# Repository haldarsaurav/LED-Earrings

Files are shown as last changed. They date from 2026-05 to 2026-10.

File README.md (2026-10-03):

# Motion-water LED earrings

This repository contains a design-start package for a rechargeable pair of 8 × 10 RGB pixel earrings. The proposed first wearable revision adds an accelerometer so a blue waterline reacts to tilt. It is intended as a personal gift project.

- [Selected plan](FINAL_PLAN.md)
- [Rev B electrical architecture, net names and PCB study](hardware/rev_b/README.md)
- [Compiled ATtiny1616 firmware and animated water preview](firmware/rev_b/README.md)
- [Parametric cases and rendered STL fit dummies](mechanical/rev_b/README.md)
- [Home programming and first-article checks](PROGRAM_AND_TEST.md)
- [Editable EasyEDA Rev B project](https://easyeda.com/haldarsaurav123456/led-earrings-rev-b-motion-water)

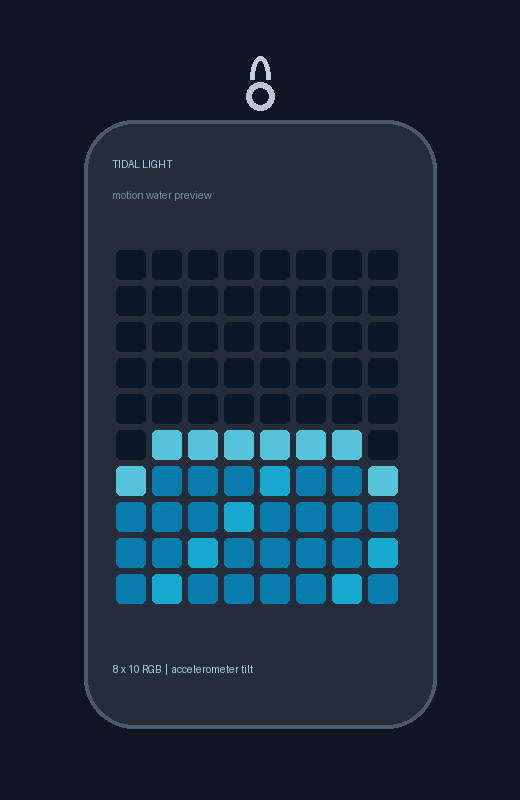
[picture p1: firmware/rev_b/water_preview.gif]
Simulated motion water effect


**Build status:** EasyEDA contains a partial schematic with the MCU, accelerometer, charger, regulator and two LEDs, plus a provisional 26 × 42 mm PCB outline with five footprints. No electrical nets, 80-LED chain, final placement or routing have been completed. Firmware compiles and a `.hex` is included, but has not been flashed to hardware. The three STL files are fit dummies; the PCB and charging dock are not ready to fabricate or use.

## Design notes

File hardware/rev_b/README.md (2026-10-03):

# Rev B — motion water earring, design-start package

**Status: architectural schematic and placement study, with a saved [EasyEDA Rev B project](https://easyeda.com/haldarsaurav123456/led-earrings-rev-b-motion-water) containing four sourced IC symbols and two LED symbols, and a provisional 26 × 42 mm PCB outline with five footprints. Not a complete schematic, routed PCB, manufacturing file, or order authorization.** The older `documents/LED_Earrings_RevA_Design_Package` is an independent ESP32-C3 / 10 × 10 concept; do not mix its netlist or charger into this revision.

## Decision for the first wearable prototype

| Item | Choice | Reason / check |
|---|---|---|
| Display | 8 × 10 WS2812B-2020-V6, 2.4 mm pitch | Dense pixel look while leaving a margin around 2 mm packages. Confirm LCSC/JLC part and footprint orientation. |
| Controller | ATtiny1616 | Already owned as a development breakout; 16 KB flash, 2 KB RAM, UPDI. Final board uses the bare IC. |
| Motion | LIS2DW12 3-axis accelerometer | Gravity gives the tilt needed for a level water surface. A gyro would require integration and more power. |
| Power | Akyga AKY0153 / LP402025, protected 1S 150 mAh, 20 × 25 × 4 mm, 5 g | PCM is built in. Verify actual delivered polarity, dimensions and charge/discharge limits; retain factory cell insulation. |
| Cell temperature | Vishay NTCAFLEX05103GL, 10 kΩ B3435 flex NTC | Fix insulated sensing head to the pouch with strain relief; verify TS/MR thresholds and charger suspension using real temperatures. |
| Charger | BQ25185 per earring, 5 V pogo input | Power path, programmable current, temperature input. Separate USB-C dock feeds each earring in parallel. |
| Regulator | TPS63030 adjustable buck-boost, nominal 3.45 V, forced PWM while on | Keeps LED, MCU and sensor on one compatible logic rail over cell discharge. This rail must be measured at both extremes; sensor maximum is 3.6 V. |
| User control | One button plus mechanical regulator enable switch | Button changes effect/brightness; switch gives true off while charging remains connected. |
| Body | 26 × 42 × 0.8 mm PCB study, 28 × 44 mm back tray | Front LEDs exposed; rear cell, NTC and electronics insulated by a removable cover. Dimensions are provisional. |

The regulator's forced-PWM feedback reference is nominally 0.5 V. A **study value** of 1.18 MΩ over 200 kΩ gives 3.45 V. Verify worst-case tolerance, switching compensation, inductor, input/output capacitors and thermal behavior from the exact TI datasheet and a test circuit before capture. The 2020 V6 LED family is specified from 3.3 V; the LIS2DW12 is specified up to 3.6 V. Do not use the regulator's power-save mode without checking its wider output tolerance.

## Schematic connectivity to capture in EasyEDA

```mermaid
flowchart LR
    dock[USB-C dock 5 V + GND] -->|separate pogo pair per earring| ch[BQ25185 IN]
    cell[Protected 1S LiPo + NTC] <-->|BAT + TS/MR| ch
    ch -->|SYS| reg[TPS63030 3.45 V]
    sw[ON/OFF switch] -->|EN| reg
    reg --> rail[3V45 rail]
    rail --> mcu[ATtiny1616]
    rail --> acc[LIS2DW12]
    rail --> leds[80 WS2812B-2020-V6]
    mcu -->|PA4 via 330R| leds
    mcu <-->|PB1/PB0 I²C| acc
    mcu <-->|PA6| button[button to GND]
    cell -->|1M / 330k divider to PA5| mcu
    updi[UPDI test pad] -->|PA0| mcu
```

### Named nets

| Net | From | To / note |
|---|---|---|
| DOCK_5V | Rear pad P1 | BQ25185 IN; add input protection/decoupling per TI application schematic. |
| GND | Rear pad P2 | Charger, regulator, MCU, sensor, every LED and battery minus. |
| BAT | Protected cell positive | BQ25185 BAT and battery divider top. Confirm protection and NTC wiring with actual cell. |
| SYS | BQ25185 SYS | TPS63030 VIN/VINA. Do not join directly to 3V45. |
| 3V45 | TPS63030 VOUT | MCU VDD, LIS2DW12 VDD/VDDIO, LED VDD, I²C pull-ups. |
| LED_DATA_0 | PA4 through 330 Ω | LED01 DIN. Each DOUT connects to next DIN through `LED_DATA_1…79`. |
| SCL/SDA | PB0/PB1 | LIS2DW12 pins 1/4, with 10 kΩ pull-ups to 3V45. CS high; SA0 low. |
| BTN | PA6 | Button to GND, MCU internal pull-up. |
| VBAT_SENSE | PA5 | 1 MΩ from BAT, 330 kΩ to GND. |
| UPDI | PA0 | Rear programming pad P3; pad is not wired in gift charging dock. |
| VTG_3V45 | 3V45 | Rear programming voltage-sense pad P4. The programmer must not drive this pad. No contact in gift dock. |
| TS_NTC | Vishay flex NTC on cell pouch | BQ25185 TS/MR. Confirm exact bias/connection from TI datasheet and verify temperature lockout. |

Place at least 100 nF close to every IC supply, bulk capacitance at LED supply injection and regulator input/output capacitors exactly as the selected TI circuit requires. The LED data chain is serpentine from the **top-left**; the generated CSV lists all 80 coordinate-to-index mappings. Keep a continuous ground plane where routing allows. The hook hole needs copper and component clearance and must carry load through the FR-4, not a solder joint.

### Power IC capture checklist

| Device | Pin-level starting connections | Value status |
|---|---|---|
| BQ25185 | IN pin 10 = DOCK_5V; SYS pin 1 = SYS; BAT pin 2 = BAT; GND pin 5 and thermal pad = GND; `/CE` pin 4 = GND; STAT1 pin 9 / STAT2 pin 3 initially available for test. | TI table gives **24 kΩ** on ILIM/VSET pin 7 for 4.2 V cell charging with 100 mA input limit. A **10 kΩ** ISET pin 8 resistor targets about 30 mA charge. TI recommends extra ISET compensation below 50 mA: resolve exact circuit before PCB release. TS/MR pin 6 connects to the pouch-mounted NTC; verify open/short and cold/hot inhibition. |
| TPS63030 | VIN pin 5 and VINA pin 8 = SYS; VOUT pin 1 = 3V45; L1 pin 4 / L2 pin 2 span the specified inductor; GND pin 9, PGND pin 3 and thermal pad = GND; PS/SYNC pin 7 = SYS for forced PWM. | EN pin 6 is switched between SYS (on) and GND (off); no floating state. FB pin 10 takes a proposed 1.18 MΩ top / 200 kΩ bottom divider for nominal 3.45 V. Match inductor and capacitors to TI's application circuit, then measure the output tolerance. |

The dock carries only 5 V and ground to each earring's charger. It must not connect its 5 V contact to BAT, SYS or 3V45. The earring on/off switch disables the regulator, leaving the charger connected so the cell can charge while the lights are off.

## PCB study and files

For a quick first-draft view, open [schematic_draft.svg](schematic_draft.svg) for the one-earring power, control and LED connections, then [board_study.svg](board_study.svg) for the proposed front/back layout. These are review drawings, not the native orderable PCB.

Run `python generate_study.py` to regenerate:

- `placements.csv`: mechanical LED centres and provisional rear block centres, in mm from the upper-left board corner.
- `led_chain.csv`: explicit 80-pixel serpentine order and net labels.
- `board_study.svg`: front/back concept map. The rear rectangles are **space reservations**, not real footprints.

**EasyEDA status:** the named project is saved in the user's account. The ATtiny1616-MNR, ST LIS2DW12TR, TI BQ25185DLHR, TI TPS63030DSKR and two Worldsemi WS2812B-2020-V6 symbols are on the schematic. A converted 26 × 42 mm two-layer PCB document contains five footprints, still outside the board outline. The schematic has no completed nets and the PCB has no placement or routing. The pin-by-pin [capture contract](PIN_CONNECTIONS.md) and [draft BOM](bom_draft.csv) are local files. The LED library footprint is named `WS2815C-2020-4P`; confirm exact pad size and pin orientation from the Worldsemi part before creating the other 78. Never order from `board_study.svg` or the partial EasyEDA project.

## Release gates before any PCB order

1. Obtain the selected Akyga cell and Vishay NTC. Confirm delivered polarity and cell ratings, fit the NTC against the pouch, then bench-test the proposed 30 mA BQ25185 charge setting, low-current compensation, TS/MR cutoff, termination and system-off behavior.
2. Buy a few exact WS2812B-2020-V6 LEDs and a LIS2DW12 breakout. Confirm LED pinout, color order, 3.45 V operation, I²C axes and the animation on a current-limited prototype.
3. Measure supply current in water, heart, sparkle, rainbow, startup, low battery and switch-off. Measure cell voltage sag, regulator voltage and skin-side temperature. Target at least two useful hours; revise brightness, cell or pixel count if measurements disagree.
4. Print the 26 × 42 mm dummy and rear tray, then weigh and wear-test with the actual cell and a 316L hook. Check button/switch access, flex, hook pull strength, charging alignment and service-pad access.
5. Capture exact components in EasyEDA, run ERC, convert to PCB, route and run DRC. Inspect every LED DIN/DOUT pin, solder mask slivers, regulator switching loop, thermal pad, dock polarity and hook clearance. Have a second net-by-net review before exporting Gerbers/BOM/CPL.
6. Order **one small prototype batch**, assemble one board, validate electrical and thermal behavior, and only then finish the matched pair and charging dock.

## Primary component references

- [Worldsemi WS2812B-2020-V6](https://www.world-semi.com/products/ws2812b-2020-v6.html)
- [Microchip ATtiny1616](https://www.microchip.com/en-us/product/ATTINY1616)
- [ST LIS2DW12 datasheet](https://www.st.com/resource/en/datasheet/lis2dw12.pdf)
- [TI BQ25185](https://www.ti.com/product/BQ25185)
- [TI TPS63030](https://www.ti.com/product/TPS63030)
- [Akyga AKY0153 battery](https://b2b.akyga.com/en/eacuxxxaky-08771-aky0153.html)
- [Vishay NTCAFLEX05103GL datasheet](https://www.vishay.com/doc/?29132=)

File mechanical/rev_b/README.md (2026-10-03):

# Rev B 3D-printable fit study

`earring_tray.scad` is a parametric rear tray for the provisional 26 × 42 mm PCB. It leaves the LED face exposed, provides a rear cell cavity, four access wells for charge/programming pads and a hole aligned with the PCB hook hole. The selected Akyga AKY0153 pouch is 20 × 25 × 4 mm, with long leads, and the Vishay flex NTC sits against it. This is a **fit study**: connector volume, lead strain relief and component heights have not been confirmed. The printed part is not electrical insulation by itself; use an additional thin insulating film between the cell and circuit.

The three `.stl` exports were rendered with OpenSCAD 2021.01 and reported as simple 3D solids. They are printable **fit dummies**. Print one in a flexible material such as TPU and adjust `clearance`, `cavity_depth` and pad positions after measuring the real PCB, cell and pogo fixture. Test fit without a cell first. The switch and button access windows must be added once their final footprints and side locations are fixed. Keep the back removable for home programming and battery replacement; do not trap a powered cell in a sealed case.

`gift_dock.scad` is a matching two-pocket desk-dock fit study. It leaves holes for two spring contacts per earring and a cavity for wiring. It is **not** a complete charger: add a separate dock PCB with USB-C 5 V input, the correct USB-C CC resistors, and two pogo pairs feeding the two BQ25185 IN/GND inputs. Keep UPDI and target-voltage pads off the daily-use dock. A keyed pocket, purchased spring-pin dimensions and verified polarity are required before charging; the model does not yet prevent a rotated earring from being inserted.

`service_jig.scad` is a separate home programming fixture study. Its three pin bores line up with P2 GND, P3 UPDI and P4 3V45 target-voltage sense. The small peg references the offset hook hole. Verify contact order with a meter and purchased pogo pins; the jig does not contain a programmer or wiring. Never connect a 5 V supply to P4.

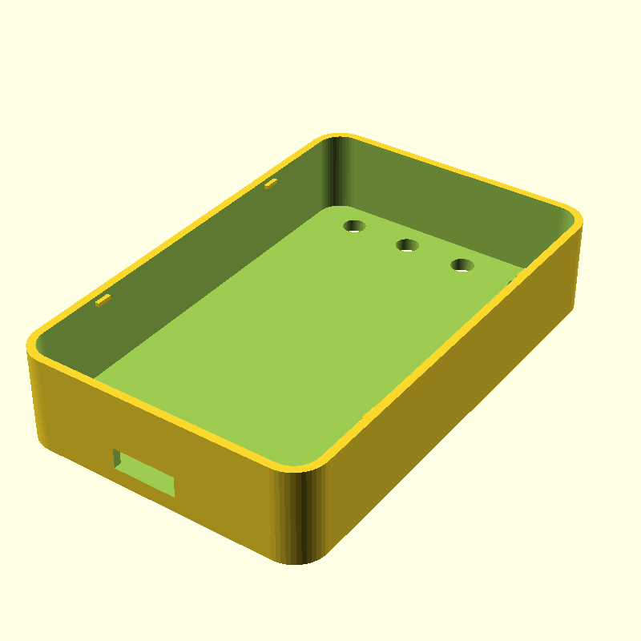
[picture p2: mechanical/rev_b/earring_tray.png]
Rendered rear tray


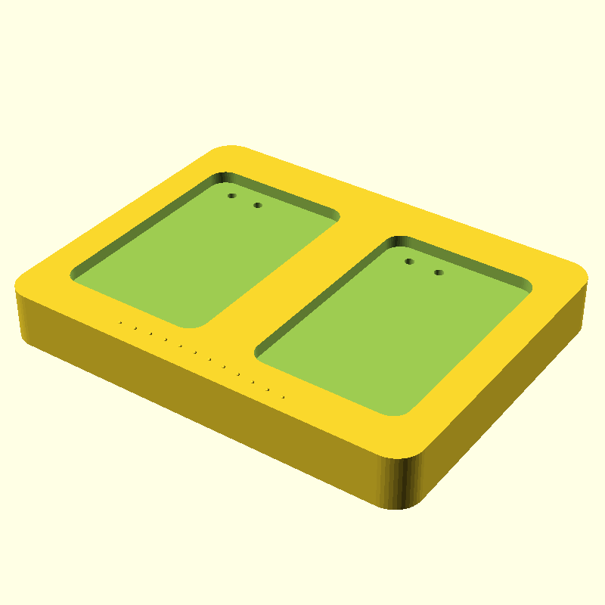
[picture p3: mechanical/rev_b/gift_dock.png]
Rendered two-pocket gift dock


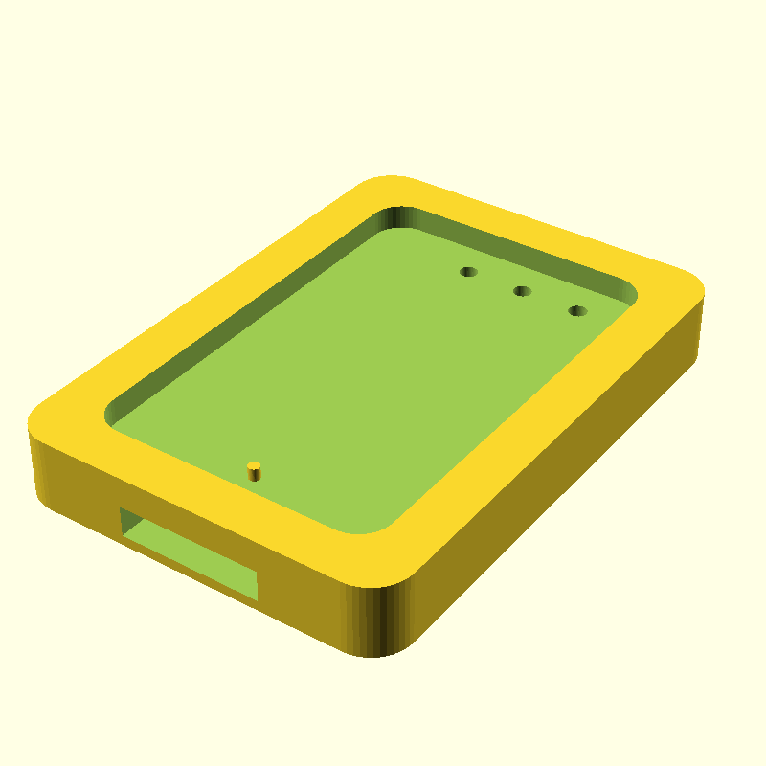
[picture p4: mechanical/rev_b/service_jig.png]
Rendered programming jig


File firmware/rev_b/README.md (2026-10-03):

# Rev B firmware — motion water earring

**Status:** compiled with Arduino CLI 1.5.2-rc.1 and megaTinyCore 2.6.11 for ATtiny1616 at 16 MHz. Build used 4537 / 16384 bytes flash and 357 / 2048 bytes static RAM. No hardware flash, current or sensor test has been performed.

## Hardware contract

| Signal | ATtiny1616 pad | Arduino name | Connection |
|---|---|---|---|
| LED_DIN | PA4 | `PIN_PA4` | 330 Ω then first WS2812B-2020-V6 DIN |
| BUTTON | PA6 | `PIN_PA6` | Normally open button to GND, internal pull-up |
| VBAT_SENSE | PA5 | `PIN_PA5` | 1 MΩ from battery, 330 kΩ to GND |
| SDA | PB1 | default Wire SDA | LIS2DW12 SDA, 10 kΩ pull-up to 3V45 |
| SCL | PB0 | default Wire SCL | LIS2DW12 SCL, 10 kΩ pull-up to 3V45 |
| UPDI | PA0 | — | Rear P3 programming pad, keep as UPDI |
| Target sense | VDD | — | Rear P4 3V45 pad for programmer voltage sensing only |

LIS2DW12 SA0 is tied to GND (I²C address 0x18); CS is tied to 3V45. The display is 8 × 10, starting at the top-left and snaking through rows. Change `SERPENTINE` or `FLIP_VERTICAL` if the actual routed chain differs. The earring's front X axis should point right and Y axis down. If sensor placement rotates the axes, adjust `readTiltTarget()`.

## Build and upload

1. Install [Arduino CLI](https://docs.arduino.cc/arduino-cli/installation) and [megaTinyCore](https://github.com/SpenceKonde/megaTinyCore). The verified build used megaTinyCore **2.6.11** and the included `tinyNeoPixel_Static` library.
2. Run `./firmware/rev_b/build.ps1` in PowerShell, or open `WaterEarring/WaterEarring.ino` in Arduino IDE. Choose ATtiny1616 at **16 MHz**, 2.6 V brown-out detector enabled and PA0 kept as UPDI. The build script records all board options and creates `WaterEarring_ATtiny1616_16MHz.hex`.
3. Compile before connecting a cell. Program through the P4 3V45, P2 GND and P3 UPDI pads with a programmer that senses target voltage. Battery installed and earring switch on. Do not feed 5 V onto 3V45. See [`PROGRAM_AND_TEST.md`](../../PROGRAM_AND_TEST.md) for the full home procedure.
4. Test one LED, then a short chain, then the full matrix from a current-limited supply. Verify color order, first pixel and sensor orientation. The firmware displays an automatic wave when the accelerometer is absent, allowing a visual bench test.

Short button press cycles water, heart, sparkle and rainbow. Long press cycles three restrained brightness budgets, now 10/16/24 channel-sum units for the 150 mAh cell. A hardware switch on the regulator enable pin is the true off control. A sustained low-battery reading blanks the LEDs until reset. The LED budget is a **software estimate**, not a certified current limit; measure real peak and average current and revise it before wearing.

For an assembled-unit check, **hold the effect button while switching on**. The first row shows one red, green and blue pixel. Column 5 is green if the LIS2DW12 responded and configured, red otherwise. Column 7 is green above 3.7 V, amber from 3.4–3.7 V and red below 3.4 V as estimated by the uncalibrated battery divider. Release the button and press it briefly to leave diagnostics. A green sensor indicator does not prove correct axis rotation; perform the tilt test separately.

`python firmware/rev_b/simulate.py` creates `water_preview.png` and `water_preview.gif`. They use the sketch's 8 × 10 surface and spring equations with a simulated tilt sweep. The animation is a visual preview, not a hardware measurement.

The checked `.hex` SHA-256 is `D03D51C9D4E94C5472F37E341999F4EA483CE88D4EE204009888D4E983B4F759`. Rebuild after any source, core or board-option change. The BOD menu choice is encoded in the build settings and may need a fuse-writing step on a blank part; confirm it when flashing with your actual UPDI programmer.

## Source basis

- [megaTinyCore ATtiny1616 pin map](https://github.com/SpenceKonde/megaTinyCore/blob/master/megaavr/variants/txy6/pins_arduino.h)
- [megaTinyCore tinyNeoPixel_Static API](https://github.com/SpenceKonde/megaTinyCore/blob/master/megaavr/extras/tinyNeoPixel.md)
- [ST LIS2DW12 datasheet](https://www.st.com/resource/en/datasheet/lis2dw12.pdf)

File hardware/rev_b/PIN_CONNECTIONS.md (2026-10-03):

# Rev B earring schematic capture contract

This is the pin-by-pin capture checklist for **one** earring. Build two identical copies. It complements `led_chain.csv`, which lists all 80 LED positions and data links. It is not an ERC-checked schematic or a manufacturing netlist.

## Power and charging

| Ref | Pin | Net or connection |
|---|---:|---|
| P1 rear pad | 1 | DOCK_5V, to U3 IN and C1 |
| P2 rear pad | 1 | GND |
| B1 protected 1S cell | + | BAT; verify connector polarity by meter |
| B1 | − | GND |
| TH1 pouch NTC 10 kΩ B3435 | 1 | U3 TS/MR |
| TH1 | 2 | GND |
| U3 BQ25185DLHR | 1 SYS | SYS; C2 and U4 VIN/VINA |
| U3 | 2 BAT | BAT; C3 and R4 high side |
| U3 | 3 STAT2 | Test point or explicit no-connect |
| U3 | 4 /CE | GND so charging is enabled when dock power is present |
| U3 | 5 GND, 11 exposed pad | GND plane |
| U3 | 6 TS/MR | TH1 to GND, thermally attached to the cell |
| U3 | 7 ILIM/VSET | R7 24 kΩ 1% to GND: 4.2 V cell / 100 mA input setting |
| U3 | 8 ISET | R6 10 kΩ 1% to GND: nominal 30 mA charge; reserve footprint for low-current compensation per TI |
| U3 | 9 STAT1 | Test point or explicit no-connect |
| U3 | 10 IN | DOCK_5V; C1 close to pin |
| U4 TPS63030DSKR | 1 VOUT | 3V45; C6/C7 output capacitors, R8 feedback top |
| U4 | 2 L2, 4 L1 | L1 1.5 µH between these pins; place very close |
| U4 | 3 PGND, 9 GND, 11 exposed pad | GND plane |
| U4 | 5 VIN, 8 VINA | SYS; C4 10 µF and C5 100 nF close to pins |
| U4 | 6 EN | SW1 common; SW1 chooses SYS (on) or GND (off), never floats |
| U4 | 7 PS/SYNC | SYS for forced PWM |
| U4 | 10 FB | Junction of R8 1.18 MΩ to 3V45 and R9 200 kΩ to GND |

C1 is 1 µF from DOCK_5V to GND; C2 10 µF SYS to GND; C3 1 µF BAT to GND. Follow the [BQ25185 datasheet](https://www.ti.com/lit/ds/symlink/bq25185.pdf) for voltage rating and capacitance after DC bias. C4 is 10 µF SYS to GND; C5 100 nF SYS to GND; C6 and C7 are each 10 µF 3V45 to GND. Follow the [TPS63030 datasheet](https://www.ti.com/lit/ds/symlink/tps63030.pdf) for the inductor saturation rating, capacitor DC-bias performance and the very short switching loop. The 3.45 V resistor pair gives an ideal 0.5 × (1 + 1.18 M / 200 k) = 3.45 V. At ±1% resistors and the specified 0.495–0.505 V forced-PWM feedback range, the simple DC divider calculation spans about **3.36–3.55 V** before layout, ripple and load transients. Measure the actual output; the sensor limit is 3.6 V and the LEDs need at least 3.3 V.

The charger datasheet recommends additional ISET compensation below 50 mA. The exact network needs a bench check at 30 mA; include nearby optional pads before a board release. Do not call this charging design validated solely from the resistor equation.

## Controller, accelerometer and LEDs

| Ref | Pin | Net or connection |
|---|---:|---|
| U1 ATtiny1616-MNR | 3 GND, 21 exposed pad | GND |
| U1 | 4 VDD | 3V45; C8 100 nF to GND at pin |
| U1 | 5 PA4 | R1 330 Ω to LED_DATA_0 = LED01 DI |
| U1 | 6 PA5 | VBAT_SENSE; R4 1 MΩ to BAT, R5 330 kΩ to GND |
| U1 | 7 PA6 | BTN1 normally open to GND, firmware internal pull-up |
| U1 | 13 PB1 | SDA; R2 10 kΩ to 3V45; U2 pin 4 |
| U1 | 14 PB0 | SCL; R3 10 kΩ to 3V45; U2 pin 1 |
| U1 | 19 PA0/UPDI | P3 rear programming pad; keep UPDI fuse function |
| U2 LIS2DW12TR | 1 SCL, 4 SDA | SCL and SDA nets above |
| U2 | 2 CS | 3V45 for I²C |
| U2 | 3 SA0 | GND for 7-bit address 0x18 |
| U2 | 5 NC | Explicit no-connect |
| U2 | 6 GND, 7 RES, 8 GND | GND |
| U2 | 9 VDD, 10 VDDIO | 3V45; C9 100 nF at the package |
| U2 | 11 INT2, 12 INT1 | Explicit no-connect in this polling firmware |
| P4 rear pad | 1 | 3V45 target-voltage sense; programmer must not drive it |
| LED01…LED80 WS2812B-2020-V6 | 4 VDD, 2 GND | 3V45 and GND; C10 10 µF bulk near array feed |
| LED01…LED80 | 3 DI, 1 DO | Follow every adjacent `DIN_net`/`DOUT_net` in `led_chain.csv`; LED80 DO is a declared no-connect |

Use the [ST LIS2DW12 datasheet](https://www.st.com/resource/en/datasheet/lis2dw12.pdf) for sensor pin 7 RES to GND and 10 kΩ I²C pull-ups. The schematic must explicitly mark unused pins so ERC can distinguish intentional no-connects from missed wires. Check Worldsemi's exact LED pin 1 mark against the chosen EasyEDA footprint **before** multiplying the symbol or generating placement files.

## Charging dock PCB

The dock is a separate USB-C **sink**, carrying USB 5 V and GND only. Put 5.1 kΩ Rd from each CC1 and CC2 pin to GND on the dock PCB. Feed both keyed pogo pairs in parallel through a suitable protected 5 V path; each earring limits its own input current to 100 mA. Align the positive spring only to P1 and the negative spring only to P2. Leave P3/P4 completely inaccessible to the gift dock. Choose the exact USB-C receptacle, ESD device, fuse and spring contacts from real mechanical drawings, then verify source detection and polarity before connecting cells. The printed dock STL is a fit dummy until those parts and the dock PCB are final.

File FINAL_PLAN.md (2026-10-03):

# LED earrings — Rev B execution plan

_3 October 2026. This is the selected direction for the next prototype. The PCB is not ready to order._

## The product

Make a matched pair of black-PCB pixel earrings, each with an 8 × 10 RGB face, a rear insulated battery tray, a small button, a hard on/off switch and a steel jump ring and hook. A motion-aware cyan “water” animation should stay roughly level as the wearer tilts; a heart and two other effects provide gift-friendly alternatives. The pair runs independently and charges in a small common USB-C dock, with separate charging circuits in the earrings.

The proposed board is **26 × 42 mm** with a 2.4 mm LED pitch. The larger outline reserves 20 × 25 mm for the selected battery plus room for its wires and service pads. This is a fit target; actual footprints and comfort testing may change it.

## Decisions

- **Controller:** ATtiny1616, using the owned breakout and UPDI programmer for bench tests. The final board uses the bare chip. The older ESP32-C3 firmware remains useful for the existing 8 × 8 matrix prototype but is not the firmware for this PCB.
- **Motion:** LIS2DW12 accelerometer. Its gravity vector supplies the tilt; the firmware adds damping so the water surface sloshes briefly when moved. A six-axis gyro is unnecessary for this effect.
- **LED:** 80 × WS2812B-2020-V6, subject to validating the exact assembly footprint and first article. All 80 share a regulated nominal 3.45 V rail.
- **Power:** Akyga AKY0153 / LP402025, protected 1S 150 mAh, 20 × 25 × 4 mm, 5 g. Retain its PCM and use a separate Vishay NTCAFLEX05103GL 10 kΩ, B3435 temperature sensor pressed against the pouch. Verify physical fit and cell documentation before ordering boards.
- **Charging:** BQ25185 on each earring, targeting 30 mA charge with 10 kΩ ISET and 100 mA input limit with 24 kΩ ILIM/VSET, pending TI low-current compensation and bench verification. Two rear pogo contacts take 5 V/GND from a keyed USB-C dock.
- **Home programming:** four rear pads: dock 5 V, GND, UPDI and target 3V45. A separate 3-pin programming jig touches GND, UPDI and 3V45, with the battery installed and switch on; the programmer senses target voltage and must not inject 5 V. The back tray remains removable.
- **Regulation:** TPS63030 buck-boost, nominal 3.45 V in forced PWM while enabled. This is a design study to keep the LEDs above their 3.3 V minimum and the sensor below its 3.6 V maximum; verify worst-case voltage with a real circuit.
- **Case:** exposed front display and a removable, insulating rear tray. The parametric 3D model is in `mechanical/rev_b`.

## Build sequence

1. **Bench proof:** use the owned ESP32-C3 and 8 × 8 matrix to preview animations. Obtain the exact 2020 LED and LIS2DW12 sample. Run the new ATtiny1616 sketch on a small chain, then a dense test display. Record LED color order and sensor axis orientation.
2. **Power proof:** obtain the specified cell and NTC, verify their dimensions, polarity, maximum charge/discharge ratings and NTC thermal contact. Build the 3.45 V regulator and 30 mA charger test circuits. Measure voltage at battery full/low, display off/on and dock connected. Measure peak and average current for every effect and brightness step. At 150 mAh and 50 mA average, 3 h is ideal arithmetic only; actual runtime and safe current must be measured.
3. **Wearability proof:** print the tray and a dummy board, place the actual cell and components, weigh the assembly and test hook strength and comfort. Adjust board outline or battery if it is thick or heavy.
4. **Native CAD:** continue the saved [EasyEDA Rev B project](https://easyeda.com/haldarsaurav123456/led-earrings-rev-b-motion-water). It has the four sourced IC symbols and two WS2812B-2020-V6 symbols plus a provisional 26 × 42 mm PCB with five footprints. Capture the parts and pin-level nets in [PIN_CONNECTIONS.md](hardware/rev_b/PIN_CONNECTIONS.md) and the other 78 LEDs, then place and route the earring and a separate two-pocket charging-dock PCB. The LED library footprint is named for WS2815C-2020-4P, so compare pad geometry and pin 1 orientation against the exact Worldsemi LED before duplication. Run ERC and DRC, inspect manufacturing output and independently check charger, regulator and all 80 LED chain links.
5. **First article:** order a small prototype batch, build one board and prove charging, cutoff, regulator stability, LED current, temperature and runtime. Revise the design before assembling and gifting the matched pair.

## Current deliverables and limits

The folder contains an ATtiny firmware sketch **compiled** with megaTinyCore 2.6.11 and a reproducible build script and HEX, an animated motion-water preview, explicit 80-LED chain map, a pin-level capture contract and draft BOM, placement CSV, front/back board study, three OpenSCAD models and rendered STL **fit dummies**, plus a home programming/test guide. The saved EasyEDA schematic and PCB are partial. There are **no Gerbers or assembly files**. Battery fit, charging, NTC contact, runtime, flashing and PCB routing remain unverified. Ordering this revision now would be premature.

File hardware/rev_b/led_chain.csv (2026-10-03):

index | reference | x | y | center_x_mm | center_y_mm | DIN_net | DOUT_net
1 | LED01 | 0 | 0 | 4.60 | 8.00 | LED_DATA_0 | LED_DATA_1
2 | LED02 | 1 | 0 | 7.00 | 8.00 | LED_DATA_1 | LED_DATA_2
3 | LED03 | 2 | 0 | 9.40 | 8.00 | LED_DATA_2 | LED_DATA_3
4 | LED04 | 3 | 0 | 11.80 | 8.00 | LED_DATA_3 | LED_DATA_4
5 | LED05 | 4 | 0 | 14.20 | 8.00 | LED_DATA_4 | LED_DATA_5
6 | LED06 | 5 | 0 | 16.60 | 8.00 | LED_DATA_5 | LED_DATA_6
7 | LED07 | 6 | 0 | 19.00 | 8.00 | LED_DATA_6 | LED_DATA_7
8 | LED08 | 7 | 0 | 21.40 | 8.00 | LED_DATA_7 | LED_DATA_8
9 | LED09 | 7 | 1 | 21.40 | 10.40 | LED_DATA_8 | LED_DATA_9
10 | LED10 | 6 | 1 | 19.00 | 10.40 | LED_DATA_9 | LED_DATA_10
11 | LED11 | 5 | 1 | 16.60 | 10.40 | LED_DATA_10 | LED_DATA_11
12 | LED12 | 4 | 1 | 14.20 | 10.40 | LED_DATA_11 | LED_DATA_12
13 | LED13 | 3 | 1 | 11.80 | 10.40 | LED_DATA_12 | LED_DATA_13
14 | LED14 | 2 | 1 | 9.40 | 10.40 | LED_DATA_13 | LED_DATA_14
15 | LED15 | 1 | 1 | 7.00 | 10.40 | LED_DATA_14 | LED_DATA_15
16 | LED16 | 0 | 1 | 4.60 | 10.40 | LED_DATA_15 | LED_DATA_16
17 | LED17 | 0 | 2 | 4.60 | 12.80 | LED_DATA_16 | LED_DATA_17
18 | LED18 | 1 | 2 | 7.00 | 12.80 | LED_DATA_17 | LED_DATA_18
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

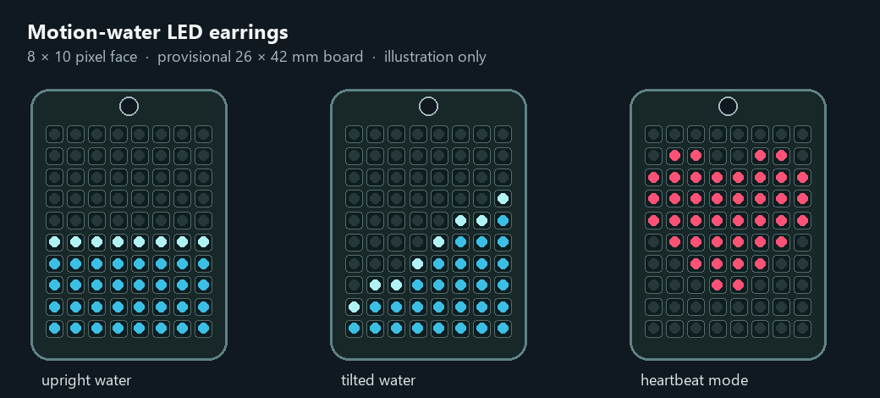
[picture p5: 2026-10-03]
hardware/rev_b/preview.png

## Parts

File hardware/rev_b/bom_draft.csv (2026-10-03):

Reference | Quantity_per_earring | Value_or_MPN | Function | Footprint_status | LCSC_or_source
U1 | 1 | ATTINY1616-MNR | Controller | EasyEDA sourced QFN-20 | C507118
U2 | 1 | LIS2DW12TR | 3-axis accelerometer | EasyEDA sourced LGA-12 | C189624
U3 | 1 | BQ25185DLHR | 1S charger with power path | EasyEDA sourced WSON-10 | C19725033
U4 | 1 | TPS63030DSKR | 3.45V buck-boost | EasyEDA sourced SON-10 | C12462
LED01-LED80 | 80 | WS2812B-2020-V6 | RGB display | Library footprint pinout UNVERIFIED | C52917434
B1 | 1 | Akyga AKY0153 150mAh protected | 1S battery | mechanical and connector fit unverified | Akyga
TH1 | 1 | Vishay NTCAFLEX05103GL | 10k B3435 cell temperature sensor | lead routing unverified | Vishay
L1 | 1 | 1.5uH rated for switch current | regulator inductor | exact MPN and footprint TBD | TBD
R1 | 1 | 330R 1% | LED data resistor | 0402 or 0603 TBD | TBD
R2-R3 | 2 | 10k 1% | I2C pullups | 0402 or 0603 TBD | TBD
R4 | 1 | 1M 1% | battery sense high | 0402 or 0603 TBD | TBD
R5 | 1 | 330k 1% | battery sense low | 0402 or 0603 TBD | TBD
R6 | 1 | 10k 1% | charger ISET nominal 30mA | 0402 or 0603 TBD | TBD
R7 | 1 | 24k 1% | charger ILIM/VSET | 0402 or 0603 TBD | TBD
R8 | 1 | 1.18M 1% | regulator feedback high | 0402 or 0603 TBD | TBD
R9 | 1 | 200k 1% | regulator feedback low | 0402 or 0603 TBD | TBD
C1 | 1 | 1uF 25V X7R | charger input | exact MPN and DC-bias TBD | TBD
C2 | 1 | 10uF 25V X7R | charger SYS | exact MPN and DC-bias TBD | TBD
C3 | 1 | 1uF X7R | charger BAT | exact MPN and DC-bias TBD | TBD
C4 | 1 | 10uF X7R | regulator VIN | exact MPN and DC-bias TBD | TBD
C5 | 1 | 100nF X7R | regulator VINA | exact MPN and footprint TBD | TBD
C6-C7 | 2 | 10uF X7R | regulator VOUT | exact MPN and DC-bias TBD | TBD
C8-C9 | 2 | 100nF X7R | MCU and sensor decoupling | exact MPN and footprint TBD | TBD
C10 | 1 | 10uF X7R | LED rail bulk | exact MPN and DC-bias TBD | TBD
BTN1 | 1 | normally open momentary | effect button | exact side-actuated part TBD | TBD
SW1 | 1 | SPDT on-off slide | regulator enable | exact side-actuated part TBD | TBD
P1-P4 | 4 | gold test pads | charge and UPDI pads | geometry and keepout TBD | PCB copper

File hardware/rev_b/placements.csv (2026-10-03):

reference | side | center_x_mm | center_y_mm | note
LED01 | front | 4.60 | 8.00 | 2.4 mm pitch; rotation TBD
LED02 | front | 7.00 | 8.00 | 2.4 mm pitch; rotation TBD
LED03 | front | 9.40 | 8.00 | 2.4 mm pitch; rotation TBD
LED04 | front | 11.80 | 8.00 | 2.4 mm pitch; rotation TBD
LED05 | front | 14.20 | 8.00 | 2.4 mm pitch; rotation TBD
LED06 | front | 16.60 | 8.00 | 2.4 mm pitch; rotation TBD
LED07 | front | 19.00 | 8.00 | 2.4 mm pitch; rotation TBD
LED08 | front | 21.40 | 8.00 | 2.4 mm pitch; rotation TBD
LED09 | front | 21.40 | 10.40 | 2.4 mm pitch; rotation TBD
LED10 | front | 19.00 | 10.40 | 2.4 mm pitch; rotation TBD
LED11 | front | 16.60 | 10.40 | 2.4 mm pitch; rotation TBD
LED12 | front | 14.20 | 10.40 | 2.4 mm pitch; rotation TBD
LED13 | front | 11.80 | 10.40 | 2.4 mm pitch; rotation TBD
LED14 | front | 9.40 | 10.40 | 2.4 mm pitch; rotation TBD
LED15 | front | 7.00 | 10.40 | 2.4 mm pitch; rotation TBD
LED16 | front | 4.60 | 10.40 | 2.4 mm pitch; rotation TBD
LED17 | front | 4.60 | 12.80 | 2.4 mm pitch; rotation TBD
LED18 | front | 7.00 | 12.80 | 2.4 mm pitch; rotation TBD
LED19 | front | 9.40 | 12.80 | 2.4 mm pitch; rotation TBD
LED20 | front | 11.80 | 12.80 | 2.4 mm pitch; rotation TBD
LED21 | front | 14.20 | 12.80 | 2.4 mm pitch; rotation TBD
LED22 | front | 16.60 | 12.80 | 2.4 mm pitch; rotation TBD
LED23 | front | 19.00 | 12.80 | 2.4 mm pitch; rotation TBD
LED24 | front | 21.40 | 12.80 | 2.4 mm pitch; rotation TBD
LED25 | front | 21.40 | 15.20 | 2.4 mm pitch; rotation TBD
LED26 | front | 19.00 | 15.20 | 2.4 mm pitch; rotation TBD
LED27 | front | 16.60 | 15.20 | 2.4 mm pitch; rotation TBD
LED28 | front | 14.20 | 15.20 | 2.4 mm pitch; rotation TBD
LED29 | front | 11.80 | 15.20 | 2.4 mm pitch; rotation TBD
LED30 | front | 9.40 | 15.20 | 2.4 mm pitch; rotation TBD
LED31 | front | 7.00 | 15.20 | 2.4 mm pitch; rotation TBD
LED32 | front | 4.60 | 15.20 | 2.4 mm pitch; rotation TBD
LED33 | front | 4.60 | 17.60 | 2.4 mm pitch; rotation TBD
LED34 | front | 7.00 | 17.60 | 2.4 mm pitch; rotation TBD
LED35 | front | 9.40 | 17.60 | 2.4 mm pitch; rotation TBD
LED36 | front | 11.80 | 17.60 | 2.4 mm pitch; rotation TBD
LED37 | front | 14.20 | 17.60 | 2.4 mm pitch; rotation TBD
LED38 | front | 16.60 | 17.60 | 2.4 mm pitch; rotation TBD
LED39 | front | 19.00 | 17.60 | 2.4 mm pitch; rotation TBD
LED40 | front | 21.40 | 17.60 | 2.4 mm pitch; rotation TBD
LED41 | front | 21.40 | 20.00 | 2.4 mm pitch; rotation TBD
LED42 | front | 19.00 | 20.00 | 2.4 mm pitch; rotation TBD
LED43 | front | 16.60 | 20.00 | 2.4 mm pitch; rotation TBD
LED44 | front | 14.20 | 20.00 | 2.4 mm pitch; rotation TBD
LED45 | front | 11.80 | 20.00 | 2.4 mm pitch; rotation TBD
LED46 | front | 9.40 | 20.00 | 2.4 mm pitch; rotation TBD
LED47 | front | 7.00 | 20.00 | 2.4 mm pitch; rotation TBD
LED48 | front | 4.60 | 20.00 | 2.4 mm pitch; rotation TBD
LED49 | front | 4.60 | 22.40 | 2.4 mm pitch; rotation TBD
LED50 | front | 7.00 | 22.40 | 2.4 mm pitch; rotation TBD
LED51 | front | 9.40 | 22.40 | 2.4 mm pitch; rotation TBD
LED52 | front | 11.80 | 22.40 | 2.4 mm pitch; rotation TBD
LED53 | front | 14.20 | 22.40 | 2.4 mm pitch; rotation TBD
LED54 | front | 16.60 | 22.40 | 2.4 mm pitch; rotation TBD
LED55 | front | 19.00 | 22.40 | 2.4 mm pitch; rotation TBD
LED56 | front | 21.40 | 22.40 | 2.4 mm pitch; rotation TBD
LED57 | front | 21.40 | 24.80 | 2.4 mm pitch; rotation TBD
LED58 | front | 19.00 | 24.80 | 2.4 mm pitch; rotation TBD
LED59 | front | 16.60 | 24.80 | 2.4 mm pitch; rotation TBD
LED60 | front | 14.20 | 24.80 | 2.4 mm pitch; rotation TBD
LED61 | front | 11.80 | 24.80 | 2.4 mm pitch; rotation TBD
LED62 | front | 9.40 | 24.80 | 2.4 mm pitch; rotation TBD
LED63 | front | 7.00 | 24.80 | 2.4 mm pitch; rotation TBD
LED64 | front | 4.60 | 24.80 | 2.4 mm pitch; rotation TBD
LED65 | front | 4.60 | 27.20 | 2.4 mm pitch; rotation TBD
LED66 | front | 7.00 | 27.20 | 2.4 mm pitch; rotation TBD
LED67 | front | 9.40 | 27.20 | 2.4 mm pitch; rotation TBD
LED68 | front | 11.80 | 27.20 | 2.4 mm pitch; rotation TBD
LED69 | front | 14.20 | 27.20 | 2.4 mm pitch; rotation TBD
LED70 | front | 16.60 | 27.20 | 2.4 mm pitch; rotation TBD
LED71 | front | 19.00 | 27.20 | 2.4 mm pitch; rotation TBD
LED72 | front | 21.40 | 27.20 | 2.4 mm pitch; rotation TBD
LED73 | front | 21.40 | 29.60 | 2.4 mm pitch; rotation TBD
LED74 | front | 19.00 | 29.60 | 2.4 mm pitch; rotation TBD
LED75 | front | 16.60 | 29.60 | 2.4 mm pitch; rotation TBD
LED76 | front | 14.20 | 29.60 | 2.4 mm pitch; rotation TBD
LED77 | front | 11.80 | 29.60 | 2.4 mm pitch; rotation TBD
LED78 | front | 9.40 | 29.60 | 2.4 mm pitch; rotation TBD
LED79 | front | 7.00 | 29.60 | 2.4 mm pitch; rotation TBD
LED80 | front | 4.60 | 29.60 | 2.4 mm pitch; rotation TBD
HOOK | mechanical | 13 | 2.7 | 1.5 mm mechanical hole, copper clearance TBD
U1_MCU | rear | 5.5 | 35.2 | ATtiny1616; provisional reservation
U2_CHARGER | rear | 11 | 35.2 | BQ25185; provisional reservation
U3_REG | rear | 17 | 35.2 | TPS63030 + inductor; provisional reservation
U4_ACCEL | rear | 22 | 35.2 | LIS2DW12; axes TBD
BAT | rear | 13 | 19 | rear 20 x 25 x 4 mm protected cell + NTC; wire space TBD
P1_5V | rear | 4 | 39.5 | rear charging pad; keyed dock
P2_GND | rear | 10 | 39.5 | rear charging/programming pad
P3_UPDI | rear | 16 | 39.5 | rear programming pad; no dock contact
P4_3V45 | rear | 22 | 39.5 | rear programmer target-voltage sense; no dock contact

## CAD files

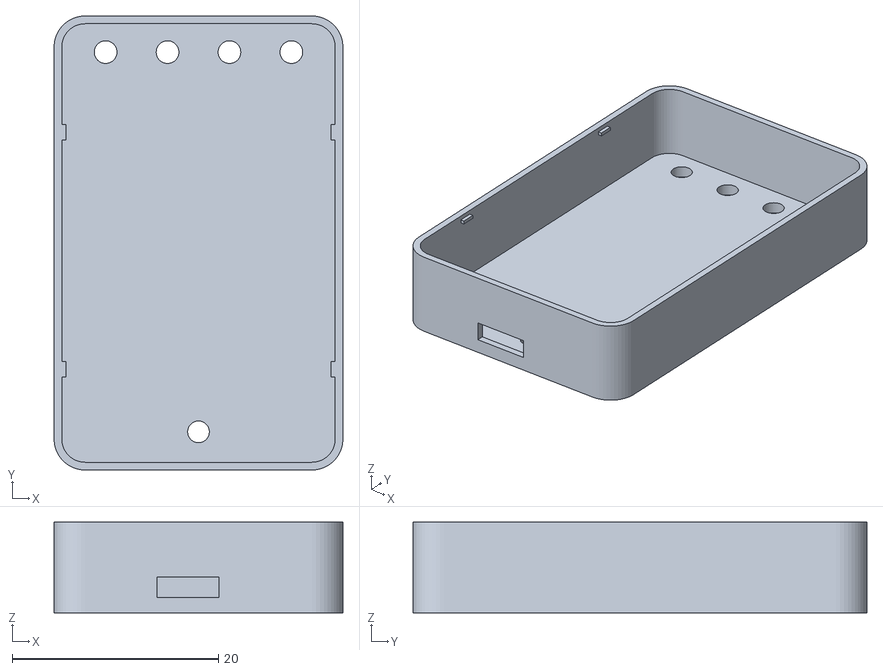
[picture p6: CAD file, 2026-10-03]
mechanical/rev_b/earring_tray.stl
28.0 x 44.0 x 8.80

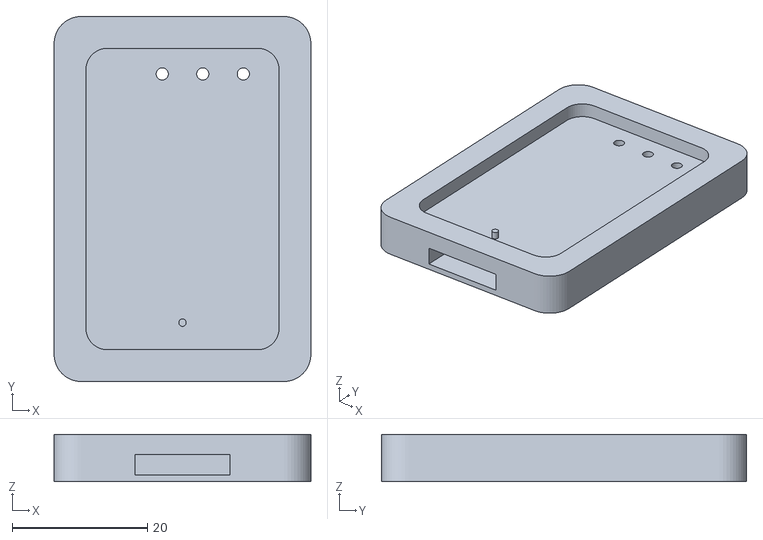
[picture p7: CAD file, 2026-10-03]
mechanical/rev_b/service_jig.stl
38.0 x 54.0 x 7.00

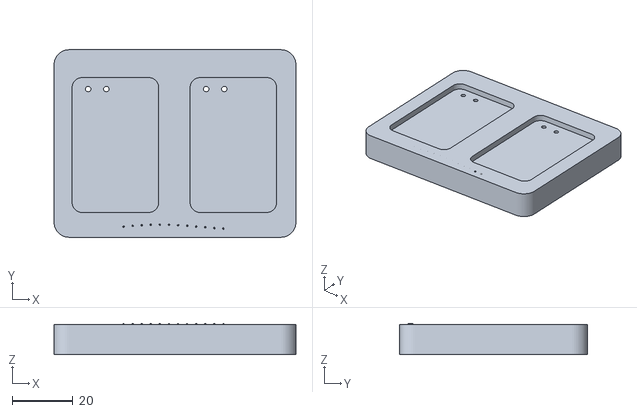
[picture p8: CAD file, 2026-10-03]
mechanical/rev_b/gift_dock.stl
80.0 x 62.0 x 10.3

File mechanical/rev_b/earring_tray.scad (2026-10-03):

// Rear tray study for one 26 x 42 mm PCB. Units: mm.
// Export an STL from OpenSCAD after adjusting measured hardware dimensions.
$fn = 48;
board_w = 26;
board_h = 42;
board_t = 0.8;
wall = 1.0;
base = 1.2;
cavity_depth = 6.8;
clearance = 0.25;
corner_r = 2.0;
hook_x = 13;
hook_y = 2.7;
hook_d = 1.5;
pad_y = 39.5;
pad_x = [4, 10, 16, 22]; // dock contacts first two; final two for UPDI + VTG

module rounded_plate(w, h, r, height) {
    linear_extrude(height=height)
        hull()
            for (x=[r, w-r], y=[r, h-r]) translate([x,y]) circle(r=r);
}

module tray() {
    difference() {
        translate([-wall,-wall,0])
            rounded_plate(board_w+2*wall, board_h+2*wall, corner_r+wall,
                          base+cavity_depth+board_t);
        // Rear component and cell cavity; board rests at its top edge.
        translate([-clearance,-clearance,base])
            rounded_plate(board_w+2*clearance,board_h+2*clearance,
                          corner_r+clearance,cavity_depth+board_t+1);
        // Mechanical hook passes through board and tray base.
        translate([hook_x,hook_y,-0.1]) cylinder(d=hook_d+0.6,h=base+0.2);
        // Rear pogo access wells. Verify diameter with actual contact tip.
        for (x=pad_x) translate([x,pad_y,-0.1]) cylinder(d=2.2,h=base+0.2);
        // Small bottom drainage/inspection slot, away from the battery.
        translate([9,-wall-0.1,1.5]) cube([6,wall+clearance+0.2,2]);
    }
    // Four flexible retention nibs; tune after the first print.
    // Nibs overlap the wall so the STL remains one connected solid.
    for (x=[-0.55,board_w-0.15], y=[8,31])
        translate([x,y,base+cavity_depth]) cube([0.7,1.5,0.35]);
}

tray();

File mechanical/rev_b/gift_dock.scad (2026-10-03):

// Two-pocket desk dock fit study. A separate USB-C PCB and real pogo pins are required.
// Board/case dimensions refer to earring_tray.scad. Units: mm.
$fn = 48;
dock_w = 80;
dock_h = 62;
dock_t = 10;
corner_r = 5;
pocket_w = 28.6;
pocket_h = 44.6;
pocket_depth = 2.3;
pocket_left = [6, 45];
pocket_bottom = 8.2;
board_origin_offset = 1.3; // board origin relative to pocket outer edge
pad_x = [4, 10, 16, 22];
pad_y = 39.5;

module rounded_plate(w,h,r,depth) {
    linear_extrude(height=depth)
        hull() for (x=[r,w-r],y=[r,h-r]) translate([x,y]) circle(r=r);
}

difference() {
    rounded_plate(dock_w,dock_h,corner_r,dock_t);
    for (left=pocket_left) {
        translate([left,pocket_bottom,dock_t-pocket_depth])
            rounded_plate(pocket_w,pocket_h,3.3,pocket_depth+0.1);
        // Two spring-pin bores in each pocket. NO UPDI contact in gift dock.
        // Pin body diameter and protrusion must be changed to purchased pins.
        for (x=[pad_x[0],pad_x[1]])
            translate([left+board_origin_offset+x,
                       pocket_bottom+board_origin_offset+pad_y,-0.1])
                cylinder(d=1.8,h=dock_t+0.2);
    }
    // Internal wire space under the two pockets. Connect both chargers to
    // one correctly rated 5 V USB-C input on a SEPARATE dock PCB.
    translate([12,24,-0.1]) cube([56,15,4.1]);
    // Rear cable exit; adjust to selected USB-C connector.
    translate([34,dock_h-6,0]) cube([12,7,5]);
}

// Decorative raised wave: shallow enough to avoid touching pocket rims.
for (i=[0:11])
    translate([23+i*3,3.5+sin(i*22)*0.7,dock_t]) sphere(d=0.55);

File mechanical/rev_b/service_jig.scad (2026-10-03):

// Three-pin home-programming fixture, geometry study only. Units: mm.
// Earring sits rear-side toward three spring contacts. Verify the final
// board/tray outline, pad order and actual pogo pin drawings before use.
$fn = 48;
jig_w = 38;
jig_h = 54;
base = 7;
pocket_w = 28.6;
pocket_h = 44.6;
pocket_depth = 2.4;
pocket_x = 4.7;
pocket_y = 4.7;
board_offset = 1.3;
pad_y = 39.5;
service_pad_x = [10,16,22]; // P2 GND, P3 UPDI, P4 VTG_3V45
pin_bore_d = 1.8;           // change to measured purchased spring-pin body

module rounded_plate(w,h,r,z) {
    linear_extrude(height=z)
        hull() for (x=[r,w-r],y=[r,h-r]) translate([x,y]) circle(r=r);
}

difference() {
    rounded_plate(jig_w,jig_h,4,base);
    translate([pocket_x,pocket_y,base-pocket_depth])
        rounded_plate(pocket_w,pocket_h,3.2,pocket_depth+0.1);
    for (x=service_pad_x)
        translate([pocket_x+board_offset+x,
                   pocket_y+board_offset+pad_y,-0.1])
            cylinder(d=pin_bore_d,h=base+0.2);
    // Lead exit points away from the earring.
    translate([12,-0.1,1]) cube([14,6,3]);
}

// A shallow locator references the off-centre hook hole. Omit if the
// finished tray covers the hole; replace with a verified keyed contour.
translate([pocket_x+board_offset+13,
           pocket_y+board_offset+2.7,base-pocket_depth])
    cylinder(d=1.1,h=1.2);

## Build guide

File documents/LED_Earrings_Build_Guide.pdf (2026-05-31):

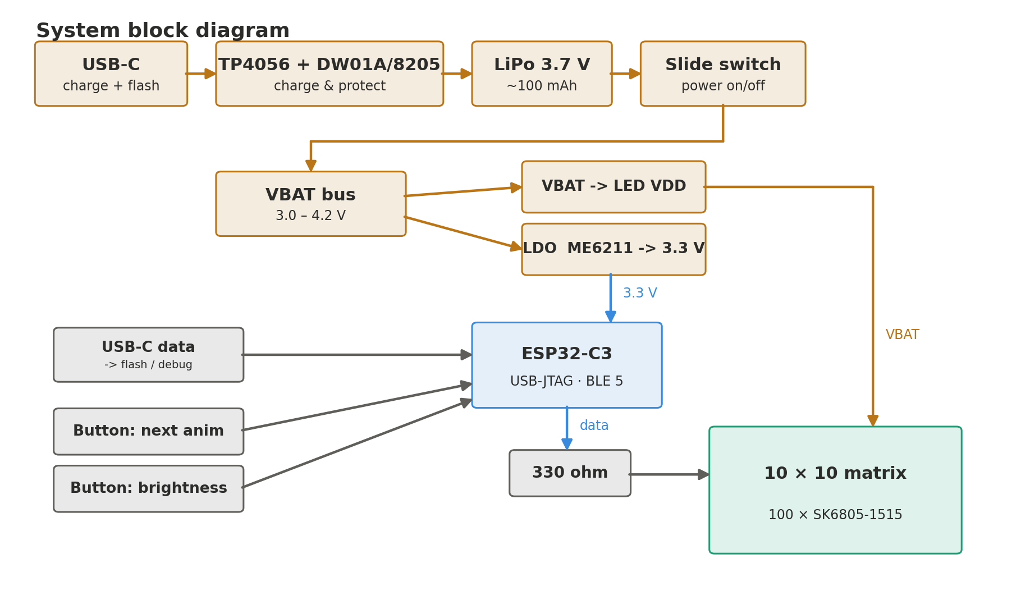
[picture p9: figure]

Pixel-Grid LED Earrings — build guide | Page 1

# Pixel-Grid LED Earrings

Build a pair of programmable, rechargeable wearable displays — from schematic to PCB to firmware.

DIFFICULTY | Intermediate–Advanced | BUILD TIME | A weekend + fab lead time
COST | ~$60–120 (small run) | SKILLS | Basic EDA, SMD or PCBA service

These earrings hang a tiny 10×10 grid of individually-addressable RGB LEDs from each ear, driven by a fingernail-sized ESP32-C3. They run smooth animations — rainbows, plasma, a pulsing heart — recharge over USB-C, and can later be controlled over Bluetooth. This guide takes you from an empty EasyEDA/KiCad canvas all the way to a finished, wearable pair, including how to order the boards and have them assembled.

## 01 How it works

The whole design follows one chain: a single LiPo cell feeds the LEDs directly (they tolerate 3.0–4.2 V) and feeds the controller through a small 3.3 V regulator. Running the LEDs straight off the battery removes two parts most beginners add by mistake — a boost converter and a logic level-shifter.

Figure 1 — One earring, end to end. Amber = power, blue = 3.3 V logic, teal = the LED matrix.

Why not WS2812B? Standard WS2812B are 5×5 mm; a 10×10 grid of them is 50×50 mm — the size of a coaster. SK6805-1515 (1.5 mm) shrink the same grid to ~17×17 mm, which is the whole reason this fits on an ear.

## 02 Bill of materials

Everything below is per earring — double it for a pair, and order ~20% spares of the small passives and LEDs (you will lose a few to rework). Confirm each exact part against your fab's in-stock library before ordering.

Part | Qty | Suggested part | Notes
LED | 100 | SK6805-1515 (or WS2812B-2020) | 1.5 mm addressable RGB
MCU | 1 | ESP32-C3FH4 (QFN32) or
| | ESP32-C3-MINI-1 | BLE 5 + USB-Serial-JTAG built in
LDO | 1 | ME6211C33M5G | 3.3 V, ~150 mV dropout
Charger | 1 | TP4056 (SOP-8) | set charge current via Rprog
Protection | 1 | DW01A + FS8205A | over-charge / discharge / current
USB | 1 | USB-C 16-pin receptacle | charge + flash
Switch | 1 | SPST slide (e.g. SK-12D07) | true power-off
Buttons | 1–2 | SMD tactile, 3×4 mm | next animation / brightness
Battery | 1 | 1S LiPo ~100 mAh (401230) | the real size constraint
Series R | 1 | 330 Ω 0402/0603 | on the LED data line
Bulk cap | 1 | 100 µF | across LED VDD at the matrix
Decoupling | ~6 | 0.1 µF 0402 | one per ~10 LEDs + per IC
Resistors | ~3 | 12 kΩ (Rprog), 10 kΩ | charge current + button pull-ups

Earring jewellery You also need the non-electronic bits: surgical-steel ear hooks, a small jump ring, optional clear acrylic/resin front to diffuse the pixels, and a thin enamelled wire or FPC tail if you split the controller onto a second board.

## 03 Tools & software

- EDA: EasyEDA (easiest path to JLCPCB) or KiCad 8 (free, more powerful).
- Firmware: VS Code + PlatformIO, or the Arduino IDE 2.x, with the FastLED library.
- Assembly: a fine-tip soldering iron + hot-air station, OR just use the fab's assembly (PCBA) service and solder nothing.
- Bench: a multimeter, ideally a USB power meter or bench supply with current limit for the first power-on.
- Tweezers, flux, solder paste, and a stencil if you reflow by hand.

## 04 Design the schematic

### 1 Capture the four blocks

Draw the circuit in the same four groups as Figure 1: charge/protect, power rails, controller, and the LED matrix. Keep each block on its own area of the sheet and label your nets (VBAT, +3V3, LED_DIN, GND) so the layout stage is readable.

### 2 Wire the key connections

USB-C VBUS → TP4056 IN+ ; TP4056 BAT+ → DW01A/FS8205A → LiPo+ Protected B+ → slide switch → VBAT rail
VBAT → ME6211 VIN ; ME6211 VOUT (3.3 V) → ESP32-C3 3V3 (1µF in & out) VBAT → LED matrix VDD (100µF bulk cap right at the matrix)
ESP32-C3 GPIO2 → 330Ω → matrix DIN
GPIO3 → NEXT button → GND ; GPIO4 → MODE button → GND
USB-C D+/D− → ESP32-C3 GPIO19/18 (native USB for flashing)

Set the charge current TP4056 charge current is Iprog = 1200 / Rprog (amps, ohms). For a tiny ~100 mAh cell aim for ~1C: a 12 kΩ Rprog gives ~100 mA and a ~1.2 h charge. Never fast-charge a cell this small.

## 05 Lay out the matrix board

The LED matrix is the visible face of the earring, so lay it out first and let everything else serve it. Place the 100 LEDs on a tight grid (1.6–1.8 mm pitch) and chain DIN→DOUT in a serpentine (boustrophedon) path so adjacent rows simply connect end-to-end.

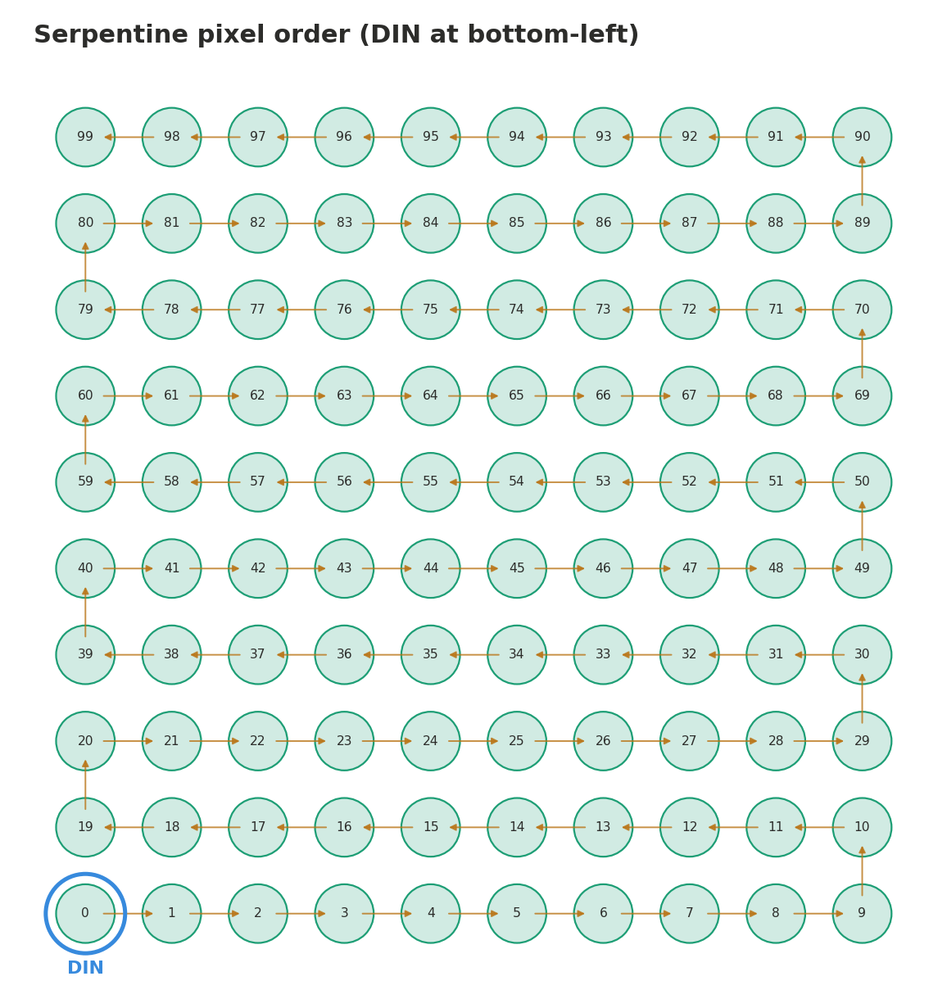
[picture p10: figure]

Figure 2 — Serpentine chain order. The number on each pixel is its index in the firmware. Match the SERPENTINE/FLIP_VERTICAL flags in config.h to however you route it.

The firmware already handles this The XY() helper in the firmware converts (x, y) coordinates to this snaking index, so every animation is matrix-agnostic. You only have to make the physical chain order match the two flags in config.h — if an effect runs sideways or upside-down, flip one of them.

## 06 Lay out the controller

- Put the ESP32-C3 module/chip, LDO, TP4056 and protection on the back of the matrix board, or on a small second board joined by a flexible tail — whichever keeps the front all-pixels.
- Give the ESP32-C3 antenna a keep-out: no copper pour under or beside the antenna end of the module.
- Keep the 330Ω series resistor and the 100µF bulk cap physically close to the matrix DIN and VDD.
- Place the USB-C connector at the bottom edge so the charging/flashing cable hangs naturally.
- Add a tiny BOOT pad (GPIO9 to GND) you can bridge if the very first flash won't enter download mode.

## 07 PCB layout tips & tricks

Decoupling Scatter 0.1µF caps along the LED chain (about one per 10 pixels) and one beside each IC. Addressable LEDs draw sharp current spikes; local caps stop the data line from glitching.

One solid ground Use a continuous ground pour on the bottom layer and tie the matrix GND back to the battery negative at a single star point. Most 'random flicker' bugs are really ground-bounce.

Protect the data line The 330Ω series resistor at the MCU end damps reflections. Keep DIN short and direct; don't run it as a long thin antenna across the board.

Let FastLED cap the current setMaxPowerInVoltsAndMilliamps() in the firmware auto-dims each frame so the panel can never pull more than your budget — this is your best defence against a full-white frame browning out the regulator. Design the copper for that capped current, not the 1.5 A theoretical max.

Width & finish Make VBAT/GND traces generous (they can carry the LED current), use ENIG finish for fine-pitch reliability, and a 2-layer 0.8 mm board to keep the earring light.

## 08 Generate fab files & order

### 1 Export the manufacturing files

From EasyEDA or KiCad export the Gerbers (copper, mask, silk, outline), the BOM (CSV) and the CPL / pick-and-place file (component positions). JLCPCB and PCBWay both want this trio for assembly.

### 2 Upload and set board options

- 2-layer, 0.8 mm thickness, ENIG finish, your smallest fab-supported trace/space.
- Order a stencil if you'll reflow yourself; skip it if you use their PCBA service.
- Check minimum drill/annular-ring rules pass design-rule-check before upload.

### 3 Pick parts for assembly (PCBA)

- Prefer the fab's Basic/Preferred parts — they cost less and skip a loading fee.
- The ESP32-C3 module and SK6805 are commonly stocked; match your footprints to their exact part numbers.
- Hand-place only what they can't: the battery, switch, ear-hook hardware.

Panelize to save money Tiny boards are cheap, but assembly has a per-order setup cost. Panelize several earrings (and a spare) into one array with mouse-bites or V-cuts so one PCBA run yields multiple pairs.

Order spares Always order at least 5 boards (the minimum is usually cheap) and extra LEDs/passives. Your first revision will have a mistake — everyone's does.

## 09 Assemble & first power-on

- If self-assembling: stencil paste, place parts, reflow on a hotplate/oven, then hand-solder the USB-C, switch and battery.
- Inspect under magnification for bridges on the QFN and the LED pads before applying any power.
- Smoke test: power from a current-limited supply (set ~150 mA) before connecting the LiPo. Confirm 3.3 V at the ESP32 and no part gets hot.
- Only then connect the battery and verify the TP4056 charges it (charge LED behaviour + rising cell voltage).

LiPo safety Never charge a swollen or damaged cell, never short the pack, and keep the protection IC in the design — not optional on a wearable. Tape/insulate the cell so a sharp edge can't pierce it inside the earring.

## 10 Flash the firmware

- Install the ESP32 board package and the FastLED library (PlatformIO: lib_deps = fastled/FastLED).
- Board = ESP32-C3; enable USB CDC On Boot so the native USB serial works.
- Plug in USB-C — the C3 enumerates directly, no FTDI/CH340 adapter needed — pick the port and Upload.
- If the first upload won't catch, bridge the BOOT pad (GPIO9→GND) while plugging in.
- To build the second earring or a different size, change MATRIX_WIDTH/HEIGHT in config.h and re-upload — nothing else.

How many animations? The ESP32-C3 has 4 MB flash and 400 KB RAM; your 100-pixel frame buffer is only 300 bytes and each effect compiles to ~0.3–2 KB. You can ship 50–200+ animations and still use under 5% of flash — the real limit is how many you feel like writing.

## 11 Power, runtime & safety

Runtime (h) = capacity(mAh) × 0.8 ÷ average current(mA). The honest constraint is weight, not cost — an earring can only carry a tiny cell, so brightness is your main runtime lever.

Battery | Brightness | Avg current | Runtime
100 mAh (401230) | low (~40) | ~70 mA | ~1.1 h
100 mAh | very low (~20) | ~45 mA | ~1.8 h
250 mAh (heavier) | low | ~90 mA | ~2.2 h

## 12 Make it wearable

- 3D-print or laser-cut a thin frame/back-shell; a frosted acrylic or thin resin layer over the front diffuses the pixels beautifully.
- Mount the LiPo and switch on the back shell, route the ear-hook through a reinforced hole or jump ring.
- Strain-relieve every wire — the USB and battery joints are what fail first on a moving wearable.
- Seal exposed metal so it can't short against hair or skin; keep total weight low for all-day comfort.

## 13 Troubleshooting

Symptom | Likely cause & fix

Colours swapped (red shows
green) | Wrong color order — change GRB to RGB in config.h.

Animation runs sideways /
upside-down | Set SERPENTINE / FLIP_VERTICAL to match your wiring.

Symptom | Likely cause & fix

First pixel works, rest are
dark/garbled | Cold joint on a DOUT→DIN hop, or missing decoupling caps.
Random flicker, worse when bright | Ground bounce / inrush — add bulk cap at matrix, lower
| PSU_MILLIAMPS.
Won't flash / no serial port | Enable USB CDC On Boot; bridge BOOT pad on first upload.
Dies after a few minutes | Battery too small or brightness too high — cap brightness in firmware.
Won't charge | Check Rprog value, TP4056 orientation, and protection-IC wiring.

Built with an ESP32-C3 + FastLED. Firmware (config.h, animations.h, LEDEarring.ino) is modular and matrix-agnostic — change two numbers to retarget any panel size. Happy building.

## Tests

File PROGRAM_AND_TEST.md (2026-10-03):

# Rev B home programming and first-article checks

This is the intended service procedure for **each** earring. The EasyEDA board and printed fixture are still drafts; confirm actual pad coordinates and polarity on the manufactured PCB before using them. Record measurements for left and right earrings separately.

## Access and tools

- Keep the rear tray removable. The four rear pads, left to right in the board study, are **P1 DOCK_5V, P2 GND, P3 UPDI, P4 VTG_3V45**. The gift dock contacts only P1 and P2. A separate, clearly marked three-pin service jig contacts P2, P3 and P4.
- Use the owned UPDI programmer only if it supports an **externally powered 3.45 V target** and voltage sensing. Connect its ground to P2, UPDI to P3 and target-voltage sense to P4. P4 is not a power input. Never connect the programmer's 5 V output or the dock's P1 to P4 or P3. Check the specific programmer's manual before wiring the jig.
- With the cell installed, switch the earring on to bring up 3V45 for programming. Measure P4 to P2 with a meter before connecting the programmer. Keep the charging dock disconnected during programming.
- The checked build is `firmware/rev_b/WaterEarring_ATtiny1616_16MHz.hex`, compiled for **ATtiny1616 at 16 MHz** with megaTinyCore **2.6.11**. `firmware/rev_b/build.ps1` reproduces it. Choose the actual compatible UPDI programmer and keep PA0 as UPDI. Set the chosen 2.6 V brown-out fuse when programming if the tool does not apply board options automatically. Save the successful core version, board settings, fuse settings and upload log in your build record. Never select a fuse setting that turns UPDI into GPIO.
- If using a Microchip programmer instead of an Arduino-compatible upload device, export a compiled `.hex` from the IDE and use that programmer's supported AVR UPDI software. Verify its target-voltage and pin mapping first. Do not assume a generic USB serial adapter can safely sense a 3.45 V target.

The service jig and tray in `mechanical/rev_b` are mechanical starts. A keyed shape and insulation around all pins must be proven with the actual spring contacts. Hold the earring still during flashing. Disconnect the jig before wearing.

## Bench sequence before connecting a cell

1. Inspect both PCB faces under magnification: LED orientation and 80-link data chain, IC pin 1 markers, QFN exposed pads, solder bridges, hook-hole clearance, charging-pad labeling and insulating film coverage.
2. With **no battery and no USB**, check resistance between GND and BAT, SYS, 3V45 and DOCK_5V. Investigate any near-short. Check that P1 is isolated from BAT/SYS/3V45 and P2 really is ground. Check that P3 reaches PA0 and P4 reaches the 3V45 rail.
3. Confirm the cell's connector polarity by meter, independent of wire colors. Confirm the actual charger footprint pin map and battery connector polarity before inserting the cell. The selected [Akyga AKY0153](https://b2b.akyga.com/en/eacuxxxaky-08771-aky0153.html) includes PCM but has no built-in temperature lead; mount the separate [Vishay flex NTC](https://www.vishay.com/doc/?29132=) flat against the pouch with insulating, temperature-appropriate adhesive and strain relief.
4. Verify the NTC reads near 10 kΩ around 25 °C and that its two leads are isolated from the cell terminals. Inspect the charger TS/MR network against the final TI design before first charge. Do not substitute a fixed resistor for a worn, rechargeable product.

## Powered bring-up

1. Prefer a current-limited bench setup with the cell disconnected for first power tests. Inject only at the approved BAT test interface, never through the exposed 3V45 sense pad, and use the regulator/charger data sheets to set safe limits. Verify rail voltages with the LEDs disabled before increasing current limit.
2. Connect the protected cell with the switch **off**. Measure BAT, SYS and P4 relative to P2. When switched on, P4 should be near the design target of 3.45 V. Test at cell full and near the chosen low-battery threshold; the LIS2DW12 supply must remain below 3.6 V and the WS2812B-2020-V6 supply above 3.3 V while active. These are release measurements, not assumed outcomes.
3. Flash firmware via P2/P3/P4. Read back/verify the programmed flash if the programmer supports it. Hold the effect button while switching on: the first row should show red, green and blue test pixels; column 5 should show green for sensor detected/configured or red for failure; column 7 shows a rough battery band. Release and tap to leave diagnostics. Confirm first pixel, serpentine order, RGB color order, button modes and water surface tilt in all orientations. If the accelerometer is absent, the water mode shows an automatic wave for a bench visual check; that fallback is not proof of I²C operation.
4. Measure **peak and average cell current** in startup, water, heart, sparkle, rainbow and all three brightness settings. Include low-cell operation and LED transitions. The selected cell is rated at 150 mAh; keep the final measured pulse and sustained current within its documented limits and PCM behavior. The firmware's brightness budget is only an estimate.
5. Check low-battery blanking, the switch-off drain, and reprogramming after full assembly. The switch should leave the charger operative but turn off the regulator and display.

## Charging and wearable checks

1. Power the dock from a known 5 V USB-C source with **no earring inserted**. Check both pogo pairs for 5 V and correct polarity. Check that there is no 5 V on either UPDI/VTG position and that reversing an earring cannot short contacts. The current dock model does not yet provide this keying, so it is a fit study only.
2. Dock one earring with its switch off. Confirm the proposed charger setting produces roughly 30 mA initial battery charge current where the cell state permits it, and that charge tapers and terminates. Repeat with the second earring and both together. Measure cell and skin-side temperatures. Test that cold/hot or disconnected NTC conditions stop charging as specified by the final charger design.
3. Run a timed discharge from full charge to firmware cutoff in the intended water mode. Record runtime, average current and outside case temperature. Aim for at least two useful hours, but use measured results to set final brightness. Charge, unplug and re-run the effect to check repeatability.
4. Weigh each complete earring, test the hook/jump-ring pull path, wear the unpowered dummy first, then the powered unit. Inspect the removable tray, cell strain relief and insulation after handling. Never wear a unit with a damaged or swollen pouch.

## PCB release record

Before ordering the PCB, attach to the EasyEDA project: exact BOM/footprints, ERC and DRC results, checked Gerbers, the verified LED chain map, pad polarity drawing, charger/NTC test result, measured rail tolerance and a photo of the cell fitting in the printed dummy. After first article, record firmware version and test measurements for both pieces. A passing design review is required before ordering the gift pair.

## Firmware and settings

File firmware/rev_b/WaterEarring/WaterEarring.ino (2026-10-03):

// Rev B concept firmware: ATtiny1616 + LIS2DW12 + 8x10 WS2812-compatible LEDs.
// Compiles with megaTinyCore 2.6.11. Flashing and physical current are unverified.
#include <Arduino.h>
#include <Wire.h>
#include <tinyNeoPixel_Static.h>

constexpr uint8_t WIDTH = 8;
constexpr uint8_t HEIGHT = 10;
constexpr uint8_t LED_COUNT = WIDTH * HEIGHT;
constexpr uint8_t LED_PIN = PIN_PA4;
constexpr uint8_t BUTTON_PIN = PIN_PA6;
constexpr uint8_t VBAT_PIN = PIN_PA5;
constexpr uint8_t SENSOR_ADDR = 0x18;
constexpr bool SERPENTINE = true;
constexpr bool FLIP_VERTICAL = false;
constexpr uint16_t FRAME_MS = 40;                 // 25 frames/s
constexpr uint16_t LOW_BATTERY_MV = 3400;        // revise from cell tests

uint8_t pixelBuffer[LED_COUNT * 3];
tinyNeoPixel strip(LED_COUNT, LED_PIN, NEO_GRB, pixelBuffer);
uint8_t mode = 0;
uint8_t budgetStep = 0;
// Start conservatively with the selected protected 150 mAh cell. These
// brightness estimates still require measured peak and average currents.
const uint8_t channelSumBudget[3] = {10, 16, 24};
bool sensorPresent = false;
bool diagnosticMode = false;
bool batteryLatchedOff = false;
int16_t slopeQ8 = 0;
int16_t slopeSpeed = 0;
uint16_t frameNumber = 0;
uint32_t lastFrame = 0;
uint32_t lowSince = 0;
bool buttonStable = HIGH;
bool buttonRaw = HIGH;
uint32_t buttonChanged = 0;
uint32_t buttonDown = 0;
bool longHandled = false;

uint8_t pixelIndex(uint8_t x, uint8_t y) {
  if (FLIP_VERTICAL) y = HEIGHT - 1 - y;
  if (SERPENTINE && (y & 1)) x = WIDTH - 1 - x;
  return y * WIDTH + x;
}

// Limit the sum of LED channel codes. This only estimates dynamic LED current.
void put(uint8_t x, uint8_t y, uint8_t r, uint8_t g, uint8_t b) {
  const uint16_t sum = (uint16_t)r + g + b;
  const uint8_t limit = channelSumBudget[budgetStep];
  if (sum > limit) {
    r = (uint16_t)r * limit / sum;
    g = (uint16_t)g * limit / sum;
    b = (uint16_t)b * limit / sum;
  }
  strip.setPixelColor(pixelIndex(x, y), r, g, b);
}

bool sensorWrite(uint8_t reg, uint8_t value) {
  Wire.beginTransmission(SENSOR_ADDR);
  Wire.write(reg);
  Wire.write(value);
  return Wire.endTransmission() == 0;
}

bool sensorRead(uint8_t reg, uint8_t *data, uint8_t length) {
  Wire.beginTransmission(SENSOR_ADDR);
  Wire.write(reg);
  if (Wire.endTransmission(false) != 0) return false;
  if (Wire.requestFrom(SENSOR_ADDR, length) != length) return false;
  for (uint8_t i = 0; i < length; ++i) data[i] = Wire.read();
  return true;
}

void startSensor() {
  uint8_t id = 0;
  sensorPresent = sensorRead(0x0F, &id, 1) && id == 0x44;
  if (!sensorPresent) return;
  // CTRL2: block-data-update + auto-increment. CTRL1: 50 Hz, LP mode 4.
  sensorPresent = sensorWrite(0x21, 0x0C) && sensorWrite(0x20, 0x43);
}

int16_t readTiltTarget() {
  if (!sensorPresent) {
    // Slow triangular slosh for bench testing without the sensor.
    const uint16_t p = frameNumber % 120;
    return p < 60 ? (int16_t)p * 8 - 240 : 720 - (int16_t)p * 8;
  }
  uint8_t raw[6];
  if (!sensorRead(0x28, raw, 6)) return slopeQ8;
  const int16_t ax = (int16_t)((uint16_t)raw[1] << 8 | raw[0]);
  const int16_t ay = (int16_t)((uint16_t)raw[3] << 8 | raw[2]);
  int32_t denominator = ay;
  if (denominator >= 0 && denominator < 8000) denominator = 8000;
  if (denominator < 0 && denominator > -8000) denominator = -8000;
  // The free surface is perpendicular to gravity: dy/dx = -ax/ay.
  int32_t target = -(int32_t)ax * 256 / denominator;
  if (target > 320) target = 320;
  if (target < -320) target = -320;
  return (int16_t)target;
}

void drawWater() {
  const int16_t target = readTiltTarget();
  // A damped spring makes the surface lag behind a moving earring.
  slopeSpeed += (target - slopeQ8) / 7 - slopeSpeed / 4;
  slopeQ8 += slopeSpeed / 4;
  for (uint8_t x = 0; x < WIDTH; ++x) {
    const int16_t dx2 = (int16_t)x * 2 - (WIDTH - 1);
    const int16_t wave = ((frameNumber + x * 7) % 23 < 5) ? 18 : 0;
    const int16_t surface = 6 * 256 + (slopeQ8 * dx2) / 2 + wave;
    for (uint8_t y = 0; y < HEIGHT; ++y) {
      const int16_t point = (int16_t)y * 256;
      if (point >= surface) put(x, y, 0, 5, 20);
      else if (point + 256 >= surface) put(x, y, 3, 11, 17);
      else put(x, y, 0, 0, 0);
    }
  }
}

void drawHeart() {
  // 8x10 pixel heart with a gentle two-beat pulse.
  static const uint8_t rows[10] = {
    0b00000000, 0b01100110, 0b11111111, 0b11111111, 0b11111111,
    0b01111110, 0b00111100, 0b00011000, 0b00000000, 0b00000000
  };
  const uint8_t phase = frameNumber % 32;
  const uint8_t red = (phase < 3 || (phase >= 7 && phase < 9)) ? 32 : 13;
  for (uint8_t y = 0; y < HEIGHT; ++y)
    for (uint8_t x = 0; x < WIDTH; ++x)
      put(x, y, rows[y] & (0x80 >> x) ? red : 0, 0, 0);
}

void drawSparkle() {
  strip.clear();
  const uint8_t a = (frameNumber * 37) % LED_COUNT;
  const uint8_t b = (frameNumber * 19 + 31) % LED_COUNT;
  strip.setPixelColor(a, 8, 4, 4);
  strip.setPixelColor(b, 3, 6, 7);
}

void drawRainbow() {
  for (uint8_t y = 0; y < HEIGHT; ++y)
    for (uint8_t x = 0; x < WIDTH; ++x) {
      const uint8_t hue = (x * 23 + y * 11 + frameNumber * 2) & 0xFF;
      // A six-sector color wheel, with restrained channel values.
      const uint8_t sector = hue / 43;
      const uint8_t ramp = (hue % 43) / 3;
      const uint8_t r = sector == 0 || sector == 5 ? 14 : (sector == 1 ? 14 - ramp : (sector == 4 ? ramp : 0));
      const uint8_t g = sector == 1 || sector == 2 ? 14 : (sector == 0 ? ramp : (sector == 3 ? 14 - ramp : 0));
      const uint8_t b = sector == 3 || sector == 4 ? 14 : (sector == 2 ? ramp : (sector == 5 ? 14 - ramp : 0));
      put(x, y, r, g, b);
    }
}

// Hold the effect button while switching on to inspect the first pixels,
// sensor response and battery state through the assembled front display.
void drawDiagnostic() {
  strip.clear();
  strip.setPixelColor(pixelIndex(0, 0), 8, 0, 0); // red
  strip.setPixelColor(pixelIndex(1, 0), 0, 8, 0); // green
  strip.setPixelColor(pixelIndex(2, 0), 0, 0, 8); // blue
  for (uint8_t y = 2; y < 6; ++y) {
    if (sensorPresent) strip.setPixelColor(pixelIndex(4, y), 0, 6, 0);
    else strip.setPixelColor(pixelIndex(4, y), 8, 0, 0);
  }
  const uint16_t mv = batteryMillivolts();
  for (uint8_t y = 2; y < 6; ++y) {
    if (mv >= 3700) strip.setPixelColor(pixelIndex(6, y), 0, 6, 0);
    else if (mv >= LOW_BATTERY_MV) strip.setPixelColor(pixelIndex(6, y), 6, 3, 0);
    else strip.setPixelColor(pixelIndex(6, y), 8, 0, 0);
  }
}

void readButton(uint32_t now) {
  const bool raw = digitalRead(BUTTON_PIN);
  if (raw != buttonRaw) { buttonRaw = raw; buttonChanged = now; }
  if (now - buttonChanged > 25 && raw != buttonStable) {
    buttonStable = raw;
    if (raw == LOW) { buttonDown = now; longHandled = false; }
    else if (!longHandled) {
      if (diagnosticMode) diagnosticMode = false;
      else mode = (mode + 1) % 4;
    }
  }
  if (buttonStable == LOW && !longHandled && now - buttonDown > 700) {
    budgetStep = (budgetStep + 1) % 3;
    longHandled = true;
  }
}

uint16_t batteryMillivolts() {
  // Divider: 1 MΩ high + 330 kΩ low. ADC reference assumed to be VDD=3.45 V.
  // 3450 * 1330 / 330 / 1023 = approximately 13.59 mV per 10-bit count.
  const uint16_t adc = analogRead(VBAT_PIN);
  return (uint32_t)adc * 13590UL / 1000UL;
}

void setup() {
  pinMode(LED_PIN, OUTPUT);
  digitalWrite(LED_PIN, LOW);
  pinMode(BUTTON_PIN, INPUT_PULLUP);
  diagnosticMode = digitalRead(BUTTON_PIN) == LOW;
  analogReadResolution(10);
  Wire.begin();
  startSensor();
  strip.clear();
  strip.show();
}

void loop() {
  const uint32_t now = millis();
  if (batteryLatchedOff) { delay(1000); return; }
  readButton(now);
  if (now - lastFrame < FRAME_MS) return;
  lastFrame = now;

  // Check roughly once per second; require a sustained low reading.
  if (frameNumber % 25 == 0) {
    if (batteryMillivolts() < LOW_BATTERY_MV) {
      if (lowSince == 0) lowSince = now;
      if (now - lowSince > 3000) {
        batteryLatchedOff = true;
        strip.clear(); strip.show();
        return;
      }
    } else lowSince = 0;
  }

  if (diagnosticMode) drawDiagnostic();
  else switch (mode) {
    case 0: drawWater(); break;
    case 1: drawHeart(); break;
    case 2: drawSparkle(); break;
    default: drawRainbow(); break;
  }
  strip.show();
  ++frameNumber;
}

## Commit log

2026-10-03 Add Rev B motion-water earring design start
    [earring_tray.scad, gift_dock.scad, led_chain.csv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]
2026-10-03 Choose protected cell and add home service workflow
    [earring_tray.scad, gift_dock.scad, led_chain.csv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]
2026-10-03 Compile motion-water firmware and export case fit models
    [bom_draft.csv, earring_tray.scad, earring_tray.stl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]
2026-10-03 Add visible schematic concept for review
